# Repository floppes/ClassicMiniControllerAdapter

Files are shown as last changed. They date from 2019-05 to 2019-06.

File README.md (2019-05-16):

# Nintendo Classic Mini Controller USB Adapter #

This is an adapter for connecting one or two Nintendo Classic Mini controllers via USB to a computer.
It works with the controllers of a Nintendo NES and SNES Classic Mini.

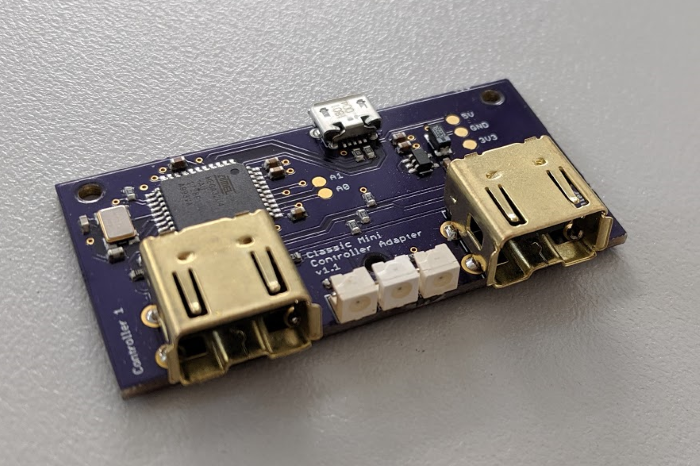
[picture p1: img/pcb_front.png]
PCB front

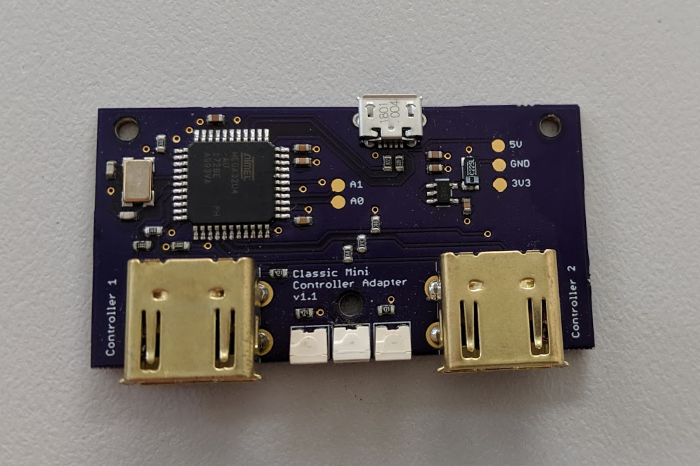
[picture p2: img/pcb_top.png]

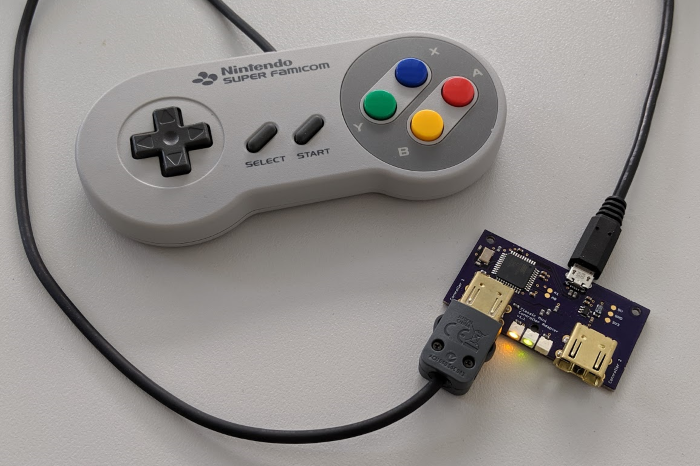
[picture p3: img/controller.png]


## Motivation ##

I like playing old retro games on a Raspberry Pi running RetroPie on my TV screen. I also have a Nintendo SNES Classic Mini and like the quality and feel of its controllers. So why not connect the controllers to the Raspberry Pi? Well, Nintendo uses their own connectors and protocol which are incompatible with a PC/laptop/Raspberry Pi. But the connectors are available to buy on the Internet and the protocol specification can be found as well. So I created a small piece of hardware around an ATmega32U4 microcontroller to translate the controller's signals to USB.

## Hardware ##

This is basically an Arduino like the Leonardo or [SparkFun Pro Micro](https://www.sparkfun.com/products/12587), running two software I2C buses. It runs at 3.3 Volts and 8 MHz.

### LEDs ###

There are three LEDs on the board. The outer yellow LEDs indicate if a controller on the corresponding port was detected. The ports are hot-pluggable. The green LED in the center indicates that the device has booted and is operational.

### PCB ###

The PCB layout and part list can be found in [schematic](schematic).

You can order the unpopulated board directly from [OSH Park](https://oshpark.com/shared_projects/MKpWshOk).

Most parts can be bought from the usual distributors such as Farnell, DigiKey, Mouser etc. The connectors are a little bit harder to get. You can find them on eBay or AliExpress if you search for **Wiimote connector**. The components cost me about $11.

## Software ##

### Bootloader ###

I recommend flashing the SparkFun Pro Micro 3.3 V/8 MHz bootloader. Add the [SparkFun board definitions](https://github.com/sparkfun/Arduino_Boards) to your Arduino IDE. You will find the instructions on their GitHub page. Use the Arduino IDE together with an AVR programmer and the backside ICSP header of the board to burn the bootloader for the 3.3 V/8 MHz variant. If you don't have an AVR programmer, you can use an Arduino with the **ArduinoISP** sketch as a programmer.

Please note that the board operates at 3.3 V. Your programmer or Arduino must work with 3.3 V logic levels. Don't use 5 V levels! If your programmer supports 5 V and 3.3 V to power the board, set it to 3.3 V. I am using the [Diamex USB ISP programmer](https://www.diamex.de/dxshop/DIAMEX-USB-ISP-Programmer-Stick-fuer-AVR) which is inexpensive and works great.

### Firmware ###

The firmware (Arduino sketch) is located in [controller_adapter](controller_adapter) and uses the awesome [joystick library](https://github.com/MHeironimus/ArduinoJoystickLibrary) written by Matthew Heironimus. You will need to download and add it to your Arduino libraries before you can compile the firmware.

After burning the bootloader, the device should appear as a SparkFun Pro Micro when connected via USB to your computer. You can then compile and download the sketch with the Arduino IDE. Select the SparkFun Pro Micro 3.3 V/8 MHz device in the Arduino IDE.

### Windows ###

Windows will detect the board as two gamepads, no further drivers needed. Any modern game should be able to use the gamepads.

### Linux ###

Linux systems will detect only one controller by default. To make Linux detect both controllers, edit the file **/boot/cmdline.txt** and add

`usbhid.quirks=0x1b4f:0x9204:0x040`

## Case ##

I have created a case to protect the PCB. The case can be printed on a 3D printer. For the top part I recommend to print it with the front down to get the LED openings right. The top and bottom parts are held together be three M2 screws.

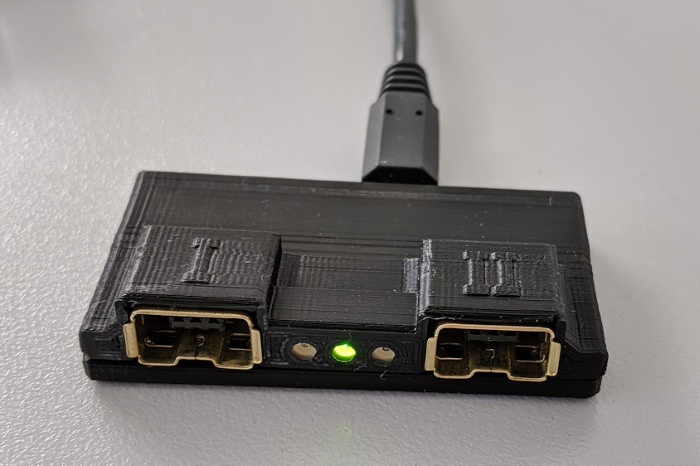
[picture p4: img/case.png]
Case


## License ##

The schematic, software and case are released under the Creative Commons BY-NC-SA 4.0 license. Check out [LICENSE.txt](LICENSE.txt) and the image link below for what you may and may not do with the files.



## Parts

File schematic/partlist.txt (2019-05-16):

Partlist

Exported from controller-adapter.sch at 16.05.2019 12:57:29

EAGLE Version 6.6.0 Copyright (c) 1988-2014 CadSoft

Assembly variant: 

Part        Value          Device            Package         Library            Sheet

C1          22pF           C0603             0603            controller-adapter 1
C2          22pF           C0603             0603            controller-adapter 1
C3          470pF          C0603             0603            controller-adapter 1
C4          2.2uF tan.     C1206             1206            controller-adapter 1
C5          100nF          C0603             0603            controller-adapter 1
C6          100nF          C0603             0603            controller-adapter 1
C7          100nF          C0603             0603            controller-adapter 1
C8          1uF            C0603             0603            controller-adapter 1
C9          1uF            C0603             0603            controller-adapter 1
C10         100nF          C0603             0603            controller-adapter 1
CONTROLLER1 WIIMOTE        WIIMOTE           WIIMOTE         controller-adapter 1
CONTROLLER2 WIIMOTE        WIIMOTE           WIIMOTE         controller-adapter 1
JP1         ICSP           JP6               JP6             controller-adapter 1
LED1        LYA67K         LEDSIDE           SIDELED         controller-adapter 1
LED2        LYA67K         LEDSIDE           SIDELED         controller-adapter 1
LED3        LGA67K         LEDSIDE           SIDELED         controller-adapter 1
R1          10K            R0603             0603            controller-adapter 1
R2          22             R0603             0603            controller-adapter 1
R3          22             R0603             0603            controller-adapter 1
R4          10K            R0603             0603            controller-adapter 1
R5          10K            R0603             0603            controller-adapter 1
R6          10K            R0603             0603            controller-adapter 1
R7          10K            R0603             0603            controller-adapter 1
R8          10K            R0603             0603            controller-adapter 1
R9          10K            R0603             0603            controller-adapter 1
R10         470            R0603             0603            controller-adapter 1
R11         470            R0603             0603            controller-adapter 1
R12         470            R0603             0603            controller-adapter 1
TP1         A1             TP1,6MM           TP1MM6          controller-adapter 1
TP2         A0             TP1,6MM           TP1MM6          controller-adapter 1
TP3         +3V3           TP1,6MM           TP1MM6          controller-adapter 1
TP4         GND            TP1,6MM           TP1MM6          controller-adapter 1
TP5         +5V            TP1,6MM           TP1MM6          controller-adapter 1
U1          ATMEGA32U4-AU  ATMEGA32U4-AU     TQFP44          controller-adapter 1
U2          MIC5219        MIC5219           SOT23-5         controller-adapter 1
X1          USB            USB_MICRO_B_MOLEX USB_MICRO_B_PIN controller-adapter 1
XT1         8MHz           XTABM3B           ABM3B           controller-adapter 1

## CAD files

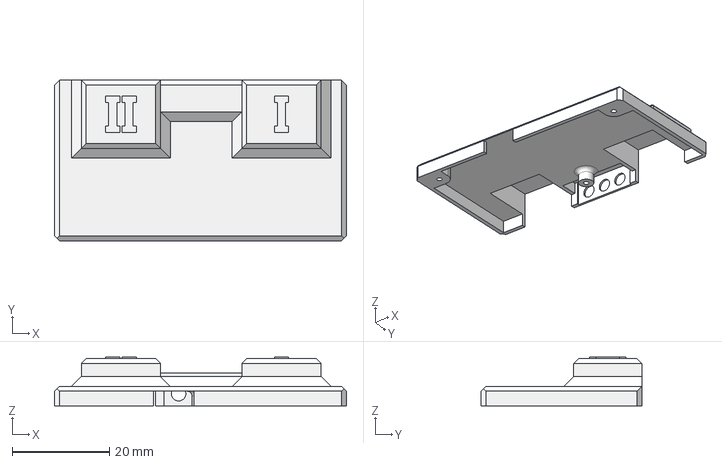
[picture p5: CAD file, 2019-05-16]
case/top.stp
60.0 x 33.0 x 10.0 mm

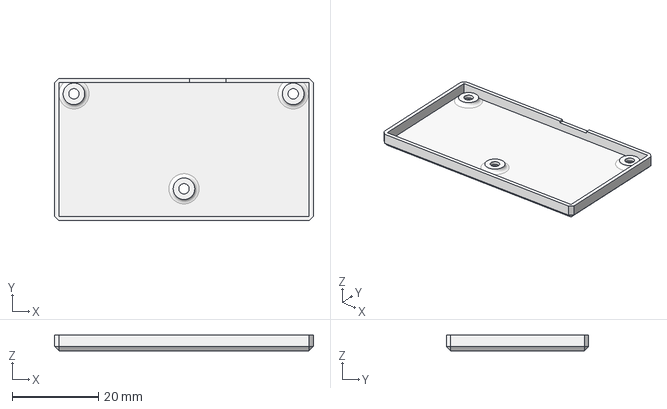
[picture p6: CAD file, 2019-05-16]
case/bottom.stp
60.0 x 33.0 x 3.60 mm

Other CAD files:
case/bottom.stl
case/top.stl

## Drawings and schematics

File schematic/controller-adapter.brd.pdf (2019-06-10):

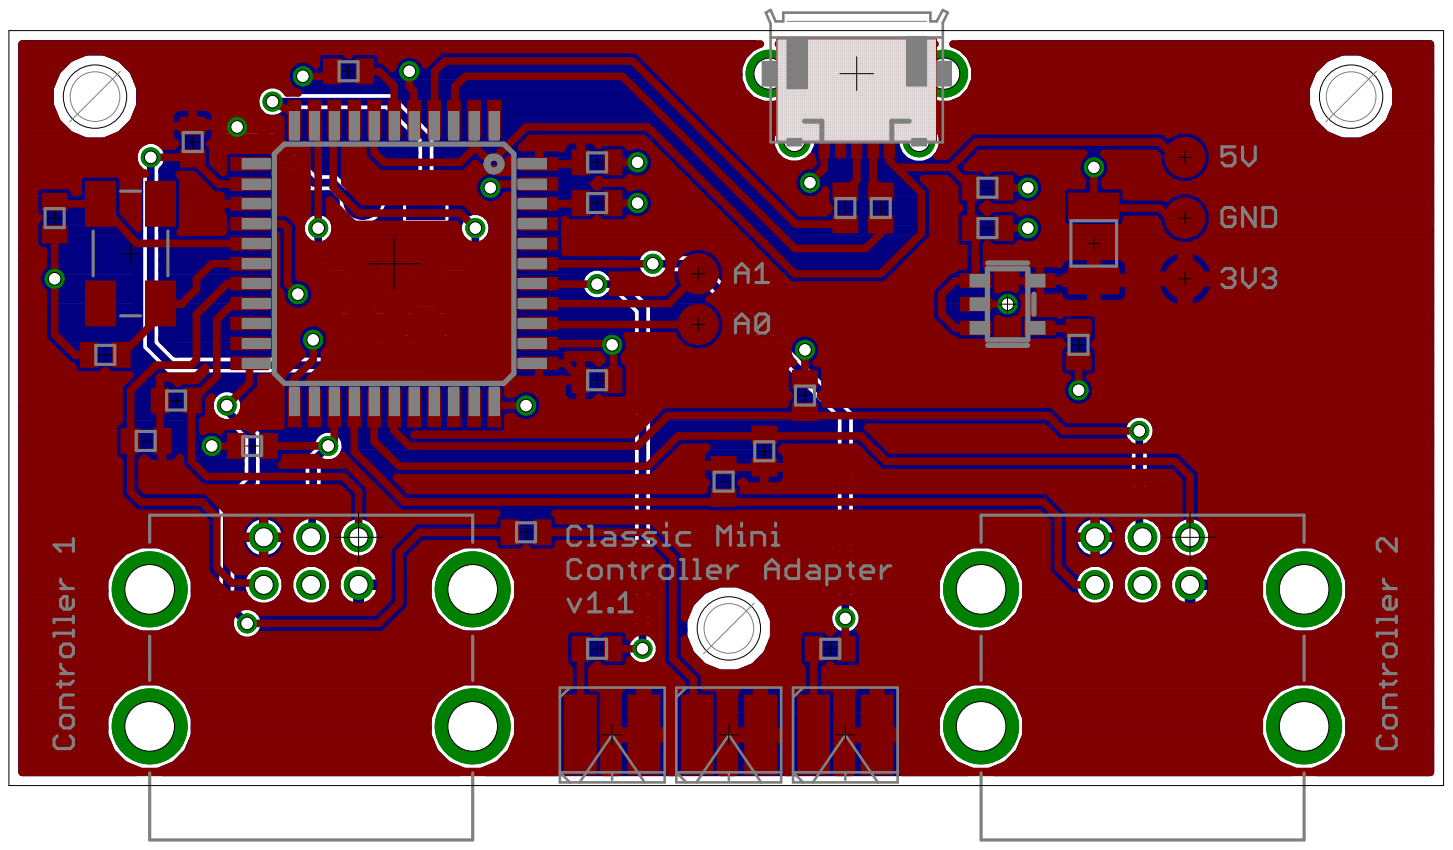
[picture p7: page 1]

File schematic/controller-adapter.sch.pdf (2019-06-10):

# C2 R¹

A

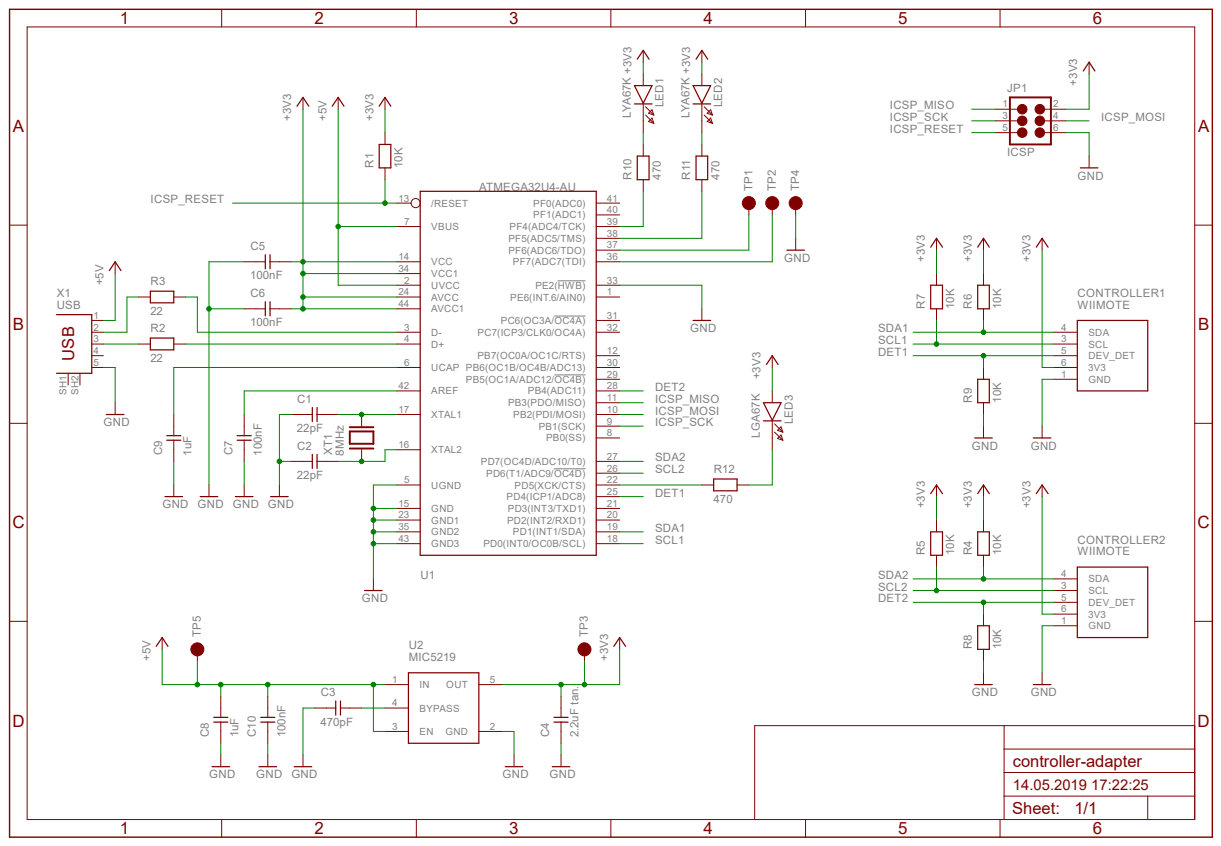
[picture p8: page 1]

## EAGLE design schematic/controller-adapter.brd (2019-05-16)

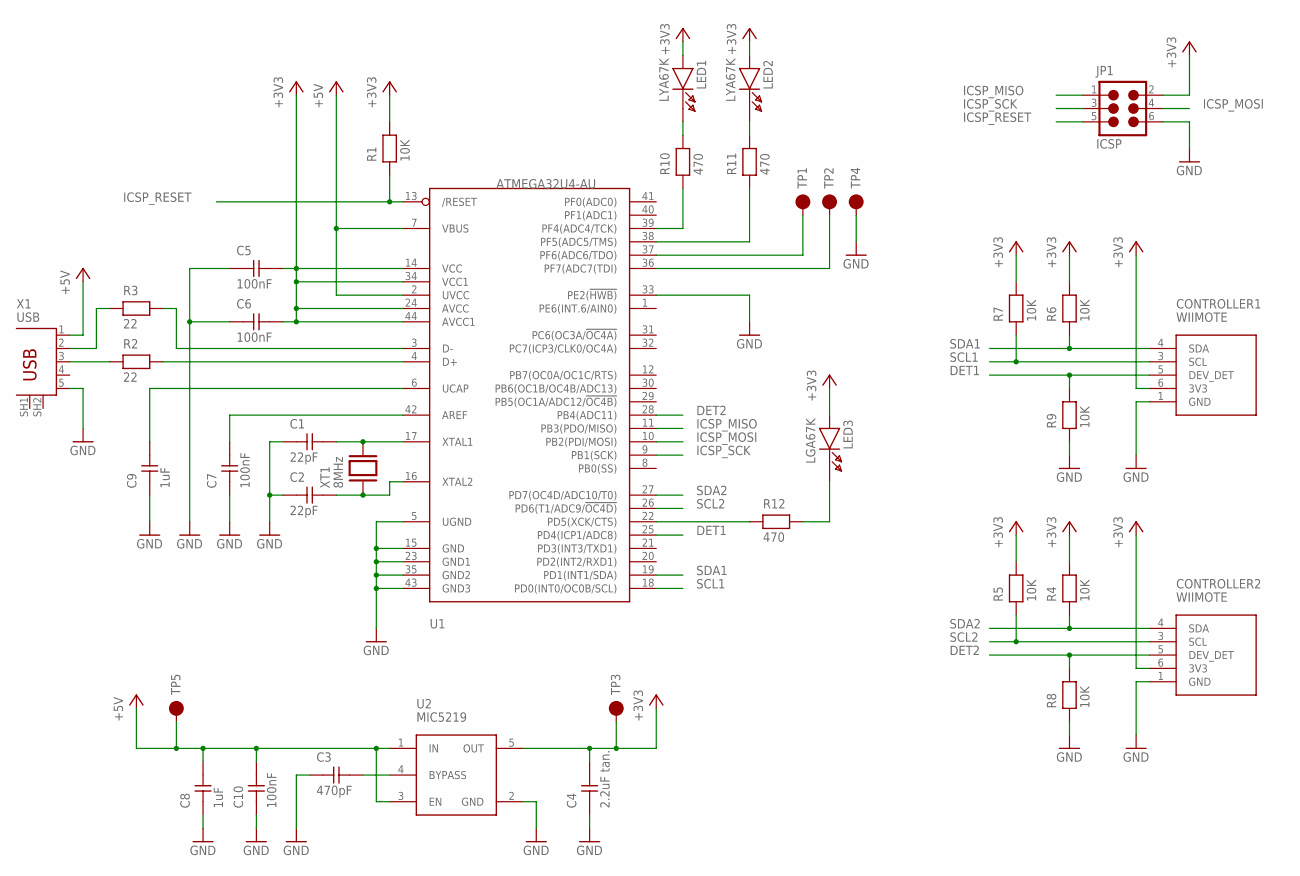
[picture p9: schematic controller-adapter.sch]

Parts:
C1, C2: 22pF; 0603
C3: 470pF; 0603
C4: 2.2uF tan.; 1206
C5, C6, C7, C10: 100nF; 0603
C8, C9: 1uF; 0603
CONTROLLER1, CONTROLLER2: WIIMOTE
JP1: ICSP; JP6
LED1, LED2: LYA67K; SIDELED
LED3: LGA67K; SIDELED
R1, R4, R5, R6, R7, R8, R9: 10K; 0603
R2, R3: 22; 0603
R10, R11, R12: 470; 0603
TP1: A1; TP1MM6
TP2: A0; TP1MM6
TP3: +3V3; TP1MM6
TP4: GND; TP1MM6
TP5: +5V; TP1MM6
U1: ATMEGA32U4-AU; TQFP44
U2: MIC5219; SOT23-5
X1: USB; USB_MICRO_B_PIN
XT1: 8MHz; ABM3B

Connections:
+3V3: C4.2, C5.2, C6.2, CONTROLLER1.6 (3V3), CONTROLLER2.6 (3V3), JP1.2, LED1.A, LED2.A, LED3.A, R1.2, R4.2, R5.2, R6.2, R7.2, TP3.1, U1.14 (VCC), U1.24 (AVCC), U1.34 (VCC1), U1.44 (AVCC1), U2.5 (OUT)
+5V: C8.2, C10.2, TP5.1, U1.2 (UVCC), U1.7 (VBUS), U2.1 (IN), U2.3 (EN), X1.1 (VBUS)
DET1: CONTROLLER1.5 (DEV_DET), R9.2, U1.25 (PD4(ICP1/ADC8))
DET2: CONTROLLER2.5 (DEV_DET), R8.2, U1.28 (PB4(ADC11))
GND: C1.1, C2.1, C3.1, C4.1, C5.1, C6.1, C7.1, C8.1, C9.1, C10.1, CONTROLLER1.1 (GND), CONTROLLER2.1 (GND), JP1.6, R8.1, R9.1, TP4.1, U1.5 (UGND), U1.15 (GND), U1.23 (GND1), U1.33 (PE2(!HWB)), U1.35 (GND2), U1.43 (GND3), U2.2 (GND), X1.5 (GND)
ICSP_MISO: JP1.1, U1.11 (PB3(PDO/MISO))
ICSP_MOSI: JP1.4, U1.10 (PB2(PDI/MOSI))
ICSP_RESET: JP1.5, R1.1, U1.13 (/RESET)
ICSP_SCK: JP1.3, U1.9 (PB1(SCK))
unnamed: C1.2, U1.17 (XTAL1), XT1.3 (2)
unnamed: C2.2, U1.16 (XTAL2), XT1.1
unnamed: TP1.1, U1.37 (PF6(ADC6/TDO))
unnamed: C3.2, U2.4 (BYPASS)
unnamed: R2.2, U1.4 (D+)
unnamed: R2.1, X1.3 (D+)
unnamed: R3.2, U1.3 (D-)
unnamed: R3.1, X1.2 (D-)
unnamed: TP2.1, U1.36 (PF7(ADC7(TDI))
unnamed: C7.2, U1.42 (AREF)
unnamed: C9.2, U1.6 (UCAP)
unnamed: R11.1, U1.38 (PF5(ADC5/TMS))
unnamed: R10.1, U1.39 (PF4(ADC4/TCK))
unnamed: LED1.K, R10.2
unnamed: LED2.K, R11.2
unnamed: R12.1, U1.22 (PD5(XCK/CTS))
unnamed: LED3.K, R12.2
SCL1: CONTROLLER1.3 (SCL), R7.1, U1.18 (PD0(INT0/OC0B/SCL))
SCL2: CONTROLLER2.3 (SCL), R5.1, U1.26 (PD6(T1/ADC9/!OC4D))
SDA1: CONTROLLER1.4 (SDA), R6.1, U1.19 (PD1(INT1/SDA))
SDA2: CONTROLLER2.4 (SDA), R4.1, U1.27 (PD7(OC4D/ADC10/T0))

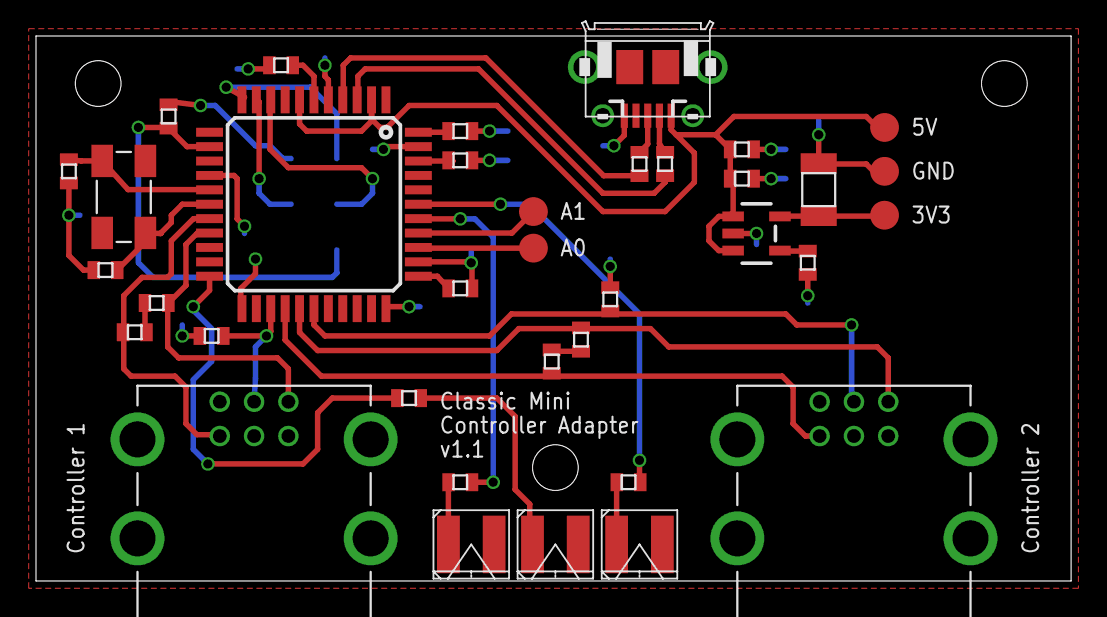
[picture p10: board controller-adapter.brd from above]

Board: 2 copper layers, 57.5 x 30.3 mm, 37 parts (1 on the bottom side), 30 nets.

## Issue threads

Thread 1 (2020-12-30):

Question: Substitute PD6/ADC9 for another pin?

mbaran5, 2020-12-30:
I was looking to see if I could wire this up to an Arduino Pro Micro that I already own and put inside of an existing (but terrible) Wii Classic to USB case, but noticed one of the pins used is PD6/ADC9 which is unused on a Pro Micro. Could another pin be substituted that isn't already in use?

Using this as my reference for which pins are mapped to which from the ATMEGA32U4: http://cdn.sparkfun.com/datasheets/Dev/Arduino/Boards/Pro_Micro_v13b.pdf

Thanks!

floppes, 2020-12-31:
Yes, that's no problem. I²C is done in software so any digital pin works. In `controller_adapter.ino` just modify the line `#define PIN_SCL2		12` to your preferred pin.

mbaran5, 2020-12-31:
Cool, thank you! I realized after posting this that both of my Pro Micros are 5v/16mhz, so I will need to rethink the plan.

Closed 2021-01-01.

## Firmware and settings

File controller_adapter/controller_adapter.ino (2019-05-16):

/**
 *	Classic Mini Controller Adapter
 *	Copyright (c) 2019 Florian Geib
 *
 *	https://github.com/floppes/ClassicMiniControllerAdapter
 *
 *	This software is distributed unter the Creative Commons BY-NC-SA 4.0 license
 */

#include <Joystick.h>
#include "i2c.h"

#define PIN_SCL1		3
#define PIN_SDA1		2
#define PIN_DET1		4
#define PIN_SCL2		12
#define PIN_SDA2		6
#define PIN_DET2		8

#define PIN_LED1		A2
#define PIN_LED2		A3

#define CONTROLLERS		2
#define BUF_LEN			6
#define ADDR			0x52

static uint8_t buffer[BUF_LEN];
static bool detected[CONTROLLERS];
static bool initialized[CONTROLLERS];
static uint16_t buttons[CONTROLLERS];
static uint8_t leds[CONTROLLERS] = { PIN_LED1, PIN_LED2 };
static uint8_t detect_pins[CONTROLLERS] = { PIN_DET1, PIN_DET2 };

static I2C i2c[CONTROLLERS] =
{
	I2C(PIN_SCL1, PIN_SDA1, ADDR),
	I2C(PIN_SCL2, PIN_SDA2, ADDR)
};

static Joystick_ Gamepads[CONTROLLERS] =
{
	Joystick_(0x03, JOYSTICK_TYPE_GAMEPAD,
	8, 0,					// button count, hat switch count
	true, true, false,		// X and Y, but no Z axis
	false, false, false,	// no Rx, Ry, or Rz
	false, false,			// no rudder or throttle
	false, false, false),	// no accelerator, brake, or steering
	Joystick_(0x04, JOYSTICK_TYPE_GAMEPAD,
	8, 0,					// button count, hat switch count
	true, true, false,		// X and Y, but no Z axis
	false, false, false,	// no Rx, Ry, or Rz
	false, false,			// no rudder or throttle
	false, false, false),	// no accelerator, brake, or steering
};

static bool initialize_controller(uint8_t controller)
{
	buffer[0] = 0xF0;
	buffer[1] = 0x55;
	
	if (!i2c[controller].write(buffer, 2))
	{
		return false;
	}
	
	delay(10);
	
	buffer[0] = 0xFB;
	buffer[1] = 0x00;
	
	if (!i2c[controller].write(buffer, 2))
	{
		return false;
	}
	
	delay(20);
	
	buffer[0] = 0xFA;
	
	if (!i2c[controller].write(buffer, 1))
	{
		return false;
	}
	
	delay(5);
	
	if (!i2c[controller].read(buffer, 6))
	{
		return false;
	}

	if ((buffer[0] != 0x01)
	 || (buffer[1] != 0x00)
	 || (buffer[2] != 0xA4)
	 || (buffer[3] != 0x20)
	 || (buffer[4] != 0x01)
	 || (buffer[5] != 0x01))
	{
		// unknown id
		return false;
	}

	return true;
}

static uint16_t read_controller(uint8_t controller)
{
	uint16_t btns;
	
	buffer[0] = 0x00;

	if (!i2c[controller].write(buffer, 1))
	{
		return 0;
	}
	
	delay(10);
	
	if (!i2c[controller].read(buffer, 6))
	{
		return 0;
	}

	btns = ~((buffer[4] << 8) + buffer[5]);

	return btns;
}

void setup()
{
	uint8_t i;

	pinMode(PIN_DET1, INPUT);
	pinMode(PIN_DET2, INPUT);
	pinMode(PIN_LED1, OUTPUT);
	pinMode(PIN_LED2, OUTPUT);

	for (i = 0; i < CONTROLLERS; i++)
	{
		digitalWrite(leds[i], HIGH);
		i2c[i].begin();
		detected[i] = false;
		initialized[i] = false;
		buttons[i] = 0x00;
		
		Gamepads[i].setXAxisRange(-1, 1);
		Gamepads[i].setYAxisRange(-1, 1);
	}
	
	for (i = 0; i < BUF_LEN; i++)
	{
		buffer[i] = 0x00;
	}

	// turn on power LED
	TXLED1;
}

void loop()
{
	uint8_t i;
	uint8_t j;
	uint16_t button;
	
	// keep power LED on
	TXLED1;

	for (i = 0; i < CONTROLLERS; i++)
	{
		if (digitalRead(detect_pins[i]))
		{
			if (!detected[i])
			{
				initialized[i] = initialize_controller(i);
				
				if (initialized[i])
				{
					detected[i] = true;
					digitalWrite(leds[i], LOW);
		
					Gamepads[i].begin(false);
				}
			}
		}
		else
		{
			if (detected[i])
			{
				detected[i] = false;
				initialized[i] = false;
				
				digitalWrite(leds[i], HIGH);
			
				Gamepads[i].end();
			}
		}

		if (detected[i] && initialized[i])
		{
			buttons[i] = read_controller(i);

			Gamepads[i].setXAxis(0);
			Gamepads[i].setYAxis(0);
		
			for (j = 0; j < 16; j++)
			{
				button = (buttons[i] >> j) & 0x0001;
			
				switch (j)
				{
					case 0:
						// Up
						if (button)
						{
							Gamepads[i].setYAxis(-1);
						}
						break;
						
					case 1:
						// Left
						if (button)
						{
							Gamepads[i].setXAxis(-1);
						}
						break;
						
					case 3:
						// X
						Gamepads[i].setButton(5, button);
						break;
						
					case 4:
						// A
						Gamepads[i].setButton(4, button);
						break;
						
					case 5:
						// Y
						Gamepads[i].setButton(1, button);
						break;
						
					case 6:
						// B
						Gamepads[i].setButton(0, button);
						break;
						
					case 9:
						// R
						Gamepads[i].setButton(7, button);
						break;
						
					case 10:
						// Start
						Gamepads[i].setButton(3, button);
						break;
						
					case 12:
						// Select
						Gamepads[i].setButton(2, button);
						break;
						
					case 13:
						// L
						Gamepads[i].setButton(6, button);
						break;
						
					case 14:
						// Down
						if (button)
						{
							Gamepads[i].setYAxis(1);
						}
						break;
						
					case 15:
						// Right
						if (button)
						{
							Gamepads[i].setXAxis(1);
						}
						break;
				}
			}
			
			Gamepads[i].sendState();
		}
	}
}

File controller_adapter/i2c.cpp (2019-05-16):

/**
 *	Classic Mini Controller Adapter
 *	Copyright (c) 2019 Florian Geib
 *
 *	https://github.com/floppes/ClassicMiniControllerAdapter
 *
 *	This software is distributed unter the Creative Commons BY-NC-SA 4.0 license
 */

#include "Arduino.h"
#include "i2c.h"

#define DELAY	20

I2C::I2C(uint8_t scl, uint8_t sda, uint8_t addr)
{
	_scl = scl;
	_sda = sda;
	_addr = addr;
}

void I2C::begin(void)
{
	pinMode(_scl, OUTPUT);
	pinMode(_sda, OUTPUT);
	
	sda_in_out = OUTPUT;
	
	digitalWrite(_scl, HIGH);
	digitalWrite(_sda, HIGH);
}

uint8_t I2C::write(uint8_t* data, uint8_t len)
{
	uint8_t i;
	
	send_start();
	
	// send address and write flag
	if (send_byte_ack(_addr << 1) == GETNAK)
	{
		return GETNAK;
	}
	
	delayMicroseconds(100);
	
	for (i = 0; i < len; i++)
	{
		if (send_byte_ack(data[i]) == GETNAK)
		{
			return GETNAK;
		}
	}
	
	send_stop();
	
	return GETACK;
}

uint8_t I2C::read(uint8_t* data, uint8_t len)
{
	uint8_t bit;
	uint8_t byte;
	uint8_t rec;
	
	send_start();
	
	// send address and read flag
	if (send_byte_ack((_addr << 1) + 1) == GETNAK)
	{
		return GETNAK;
	}
	
	delayMicroseconds(50);
	
	for (byte = 0; byte < len; byte++)
	{
		pinMode(_sda, INPUT);
		sda_in_out = INPUT;
	
		rec = 0;
		
		for (bit = 0; bit < 8; bit++)
		{
			scl_set(LOW);
			scl_set(HIGH);

			rec = (rec << 1) + digitalRead(_sda);
		}
		
		data[byte] = rec;
		
		if (byte == len - 1)
		{
			// last byte received, send NAK
			scl_set(LOW);
			sda_set(HIGH);
			scl_set(HIGH);
			scl_set(LOW);
			send_stop();
		}
		else
		{
			// receive more bytes, send ACK
			scl_set(LOW);
			sda_set(LOW);
			scl_set(HIGH);
			scl_set(LOW);
		}
	}
	
	return GETACK;
}

void I2C::sda_set(uint8_t state)
{
	if (sda_in_out != OUTPUT)
	{
		sda_in_out = OUTPUT;
		pinMode(_sda, OUTPUT);
	}
	
	digitalWrite(_sda, state);
	delayMicroseconds(DELAY);
}

void I2C::scl_set(uint8_t state)
{
	digitalWrite(_scl, state);
	delayMicroseconds(DELAY);
}

uint8_t I2C::get_ack(void)
{
	scl_set(LOW); 
	pinMode(_sda, INPUT);
	sda_in_out = INPUT;
	
	scl_set(HIGH);
	
	unsigned long timer_t = micros();
	
	while (true)
	{
		if (!digitalRead(_sda))
		{
			return GETACK;
		}
		
		if (micros() - timer_t > 100)
		{
			// timeout
			return GETNAK;
		}
	}
}

void I2C::send_start(void)
{
	sda_set(LOW);
}

void I2C::send_stop(void)
{
	scl_set(LOW);
	sda_set(LOW);
	scl_set(HIGH);
	sda_set(HIGH);
}

void I2C::send_byte(uint8_t data)
{
	uint8_t i;
	
	for (i = 0; i < 8; i++)
	{
		scl_set(LOW);
		sda_set((data & 0x80) != 0);
		data <<= 0;
		scl_set(HIGH);
		sda_set((data & 0x80) != 0);
		data <<= 1;
	}
}

uint8_t I2C::send_byte_ack(uint8_t data)
{
	send_byte(data);
	
	return get_ack();
}
